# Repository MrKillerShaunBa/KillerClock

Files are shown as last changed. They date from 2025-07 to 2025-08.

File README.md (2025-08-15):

# KillerClock

This is a Nixie tube-inspired clock made using LED filaments. These filaments are strings of micro-LEDs which imitate the look of a tungsten filament. It uses ESP-32, which syncs time with an NTP server using the on-board wifi. It uses a MAX7219 ic to run the 7 segments. Everything is powered using a 5V 2A wall adaptor. There are also Glass test tubes to match the look of a Nixie tube.

I got the inspiration when I chanced upon a [Nixie tube clock](https://nixieshop.com/), which I found very interesting. Since Nixie tubes aren't available reliably in India, I made one using LEDs.

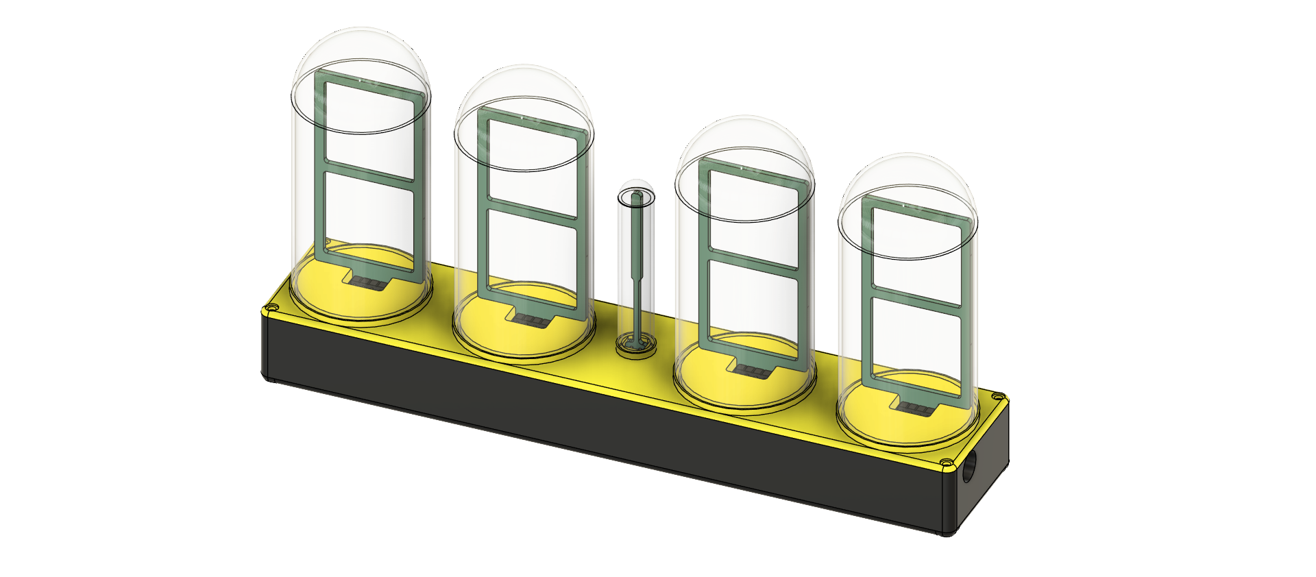
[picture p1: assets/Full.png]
Full


## CAD

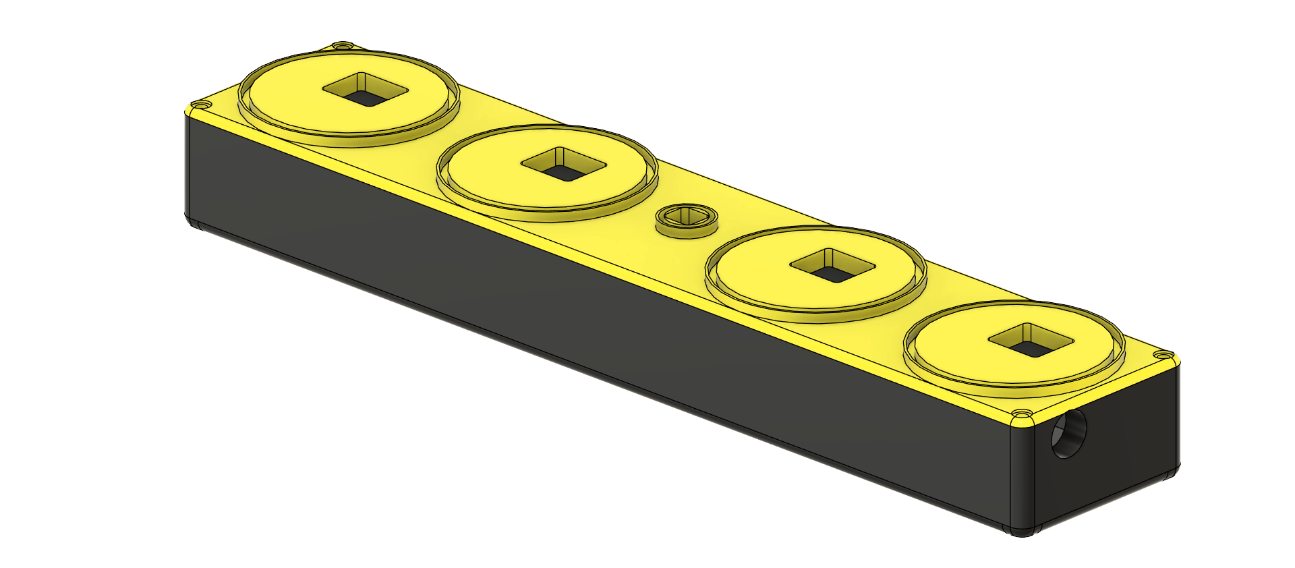
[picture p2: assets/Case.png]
Case


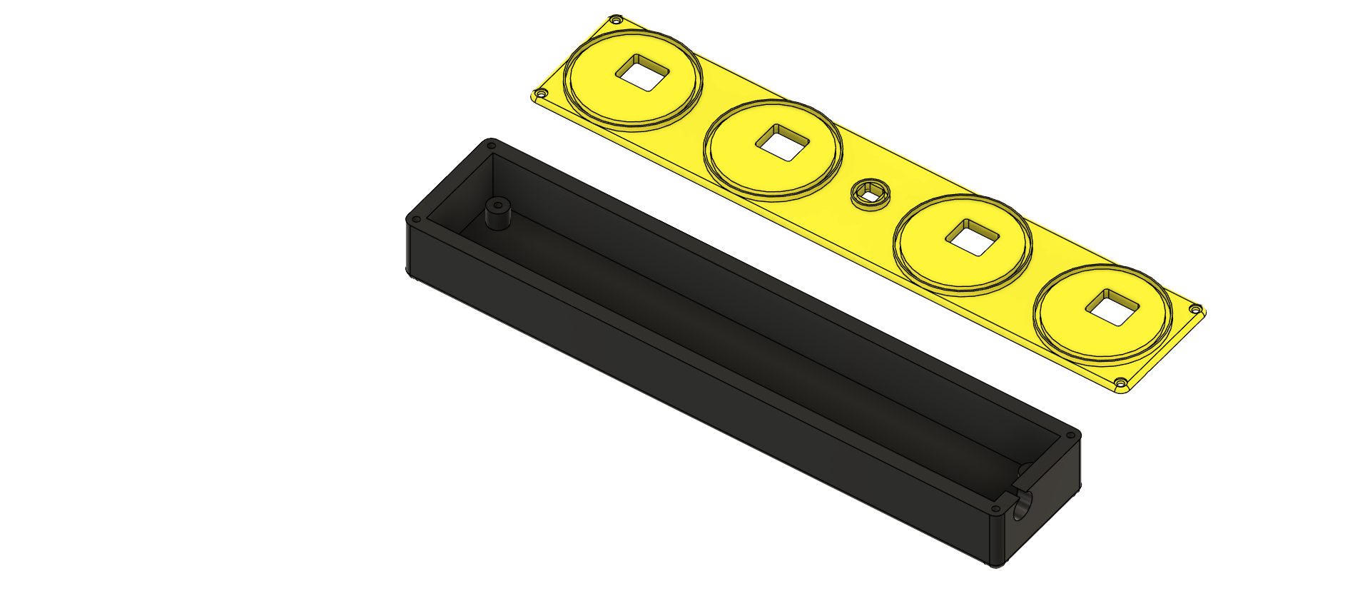
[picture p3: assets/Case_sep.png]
Case Parts


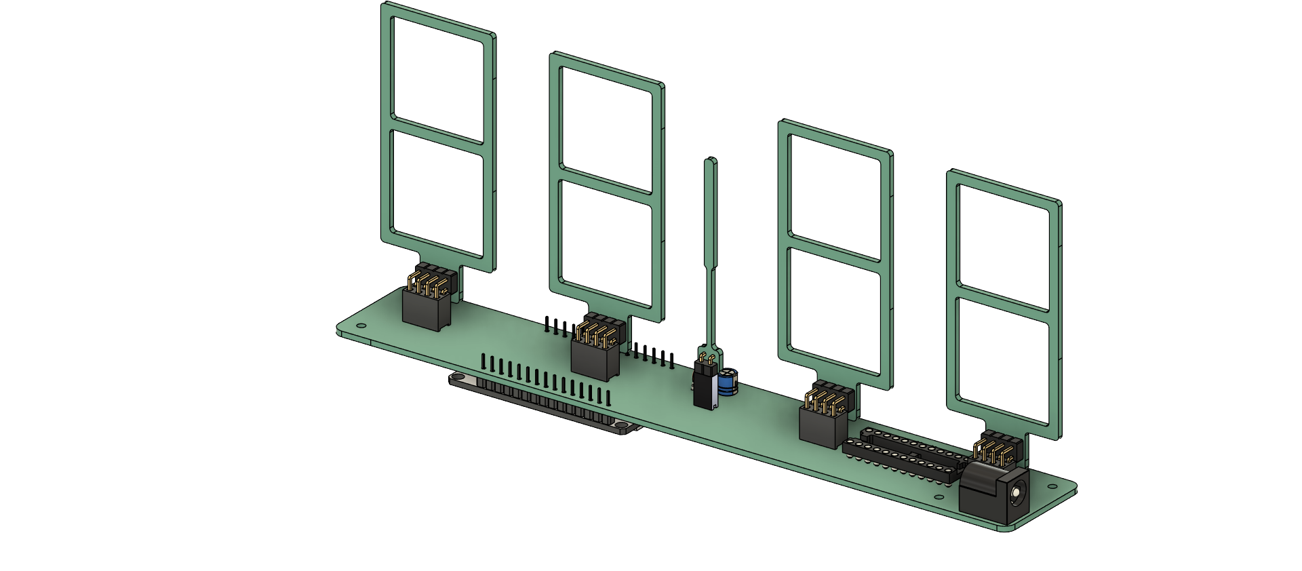
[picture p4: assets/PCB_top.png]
PCB Top


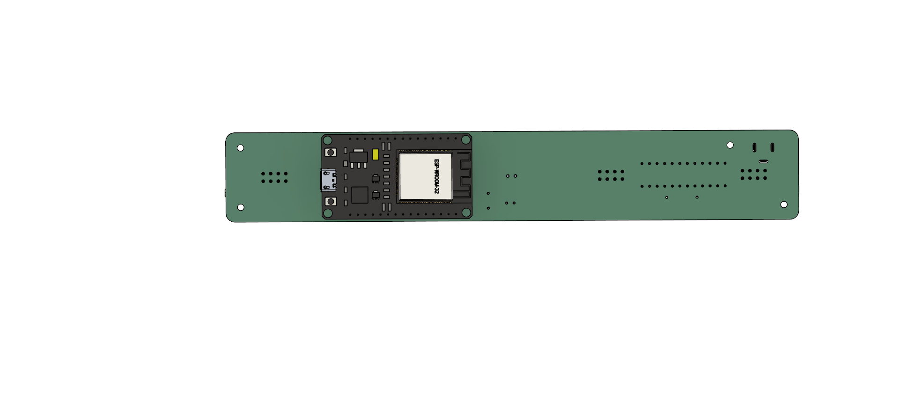
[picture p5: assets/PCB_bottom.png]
PCB Bottom


## PCB

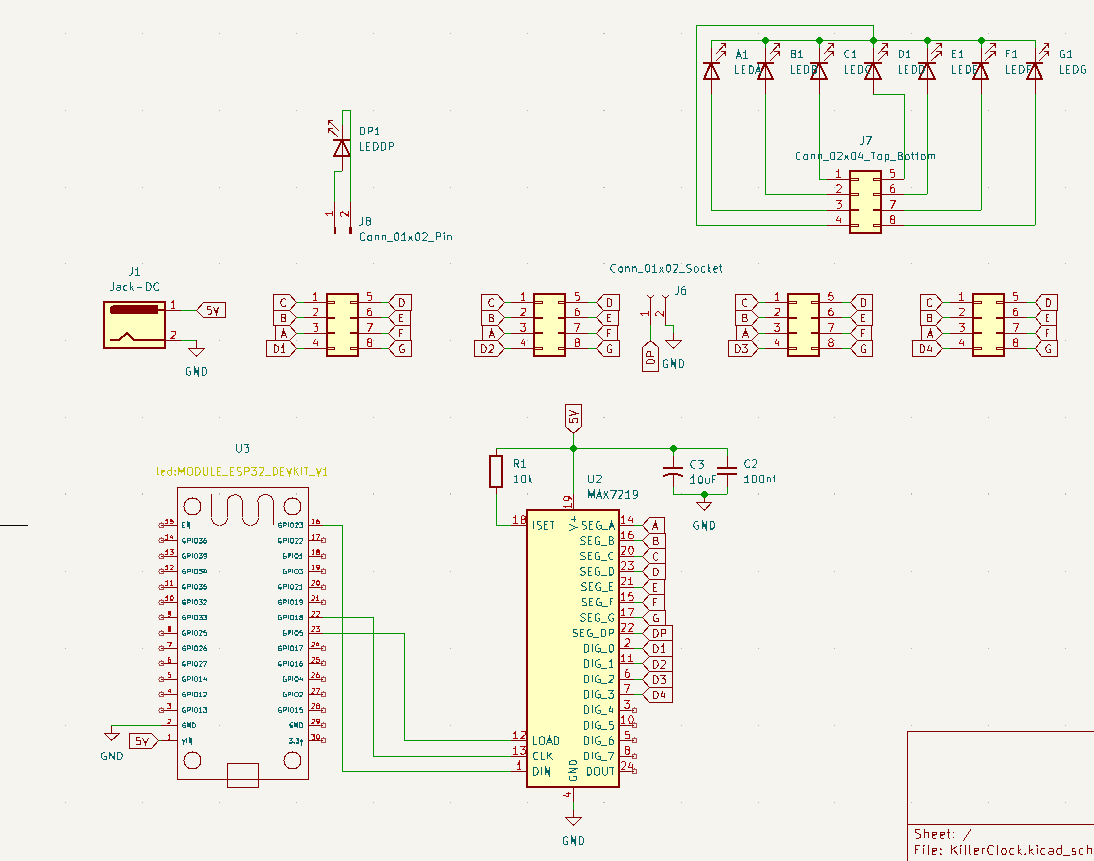
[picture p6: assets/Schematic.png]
Schematic


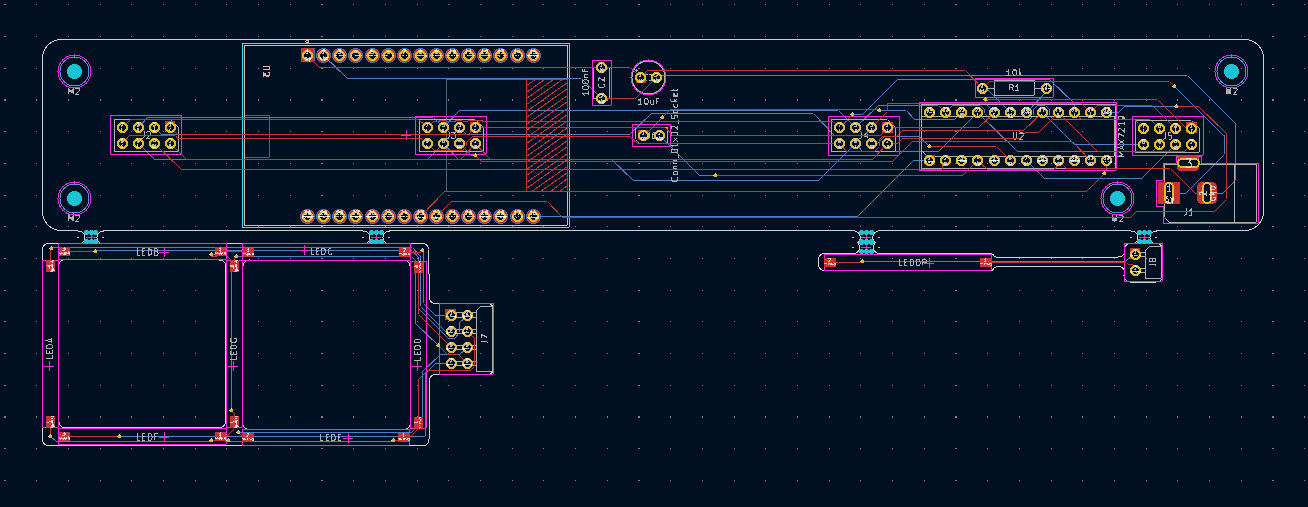
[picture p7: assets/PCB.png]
PCB


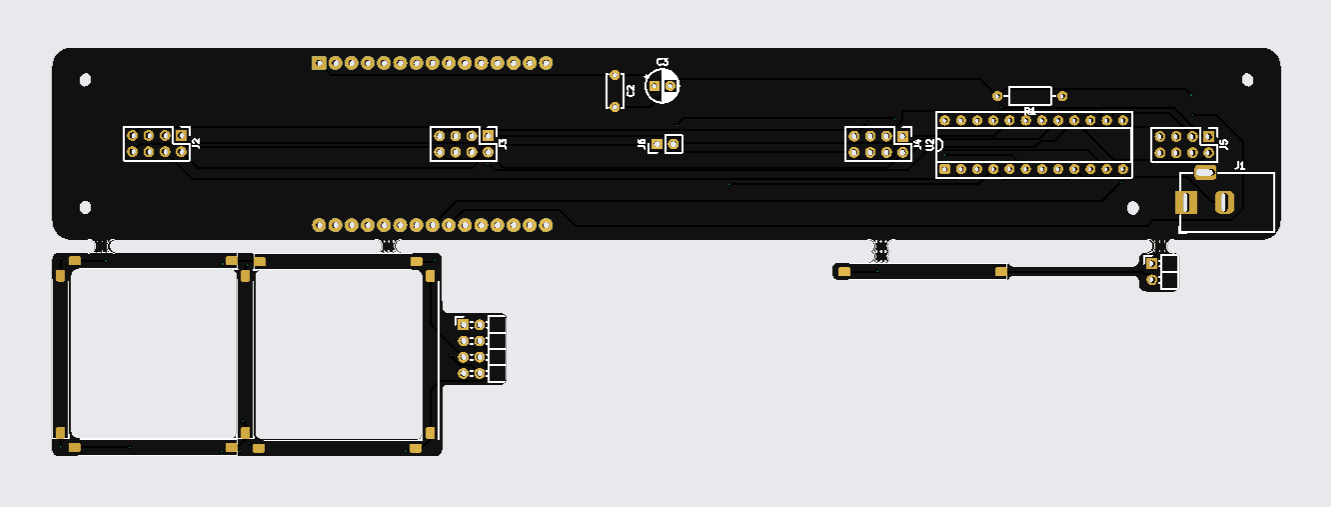
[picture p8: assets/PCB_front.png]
PCB Front


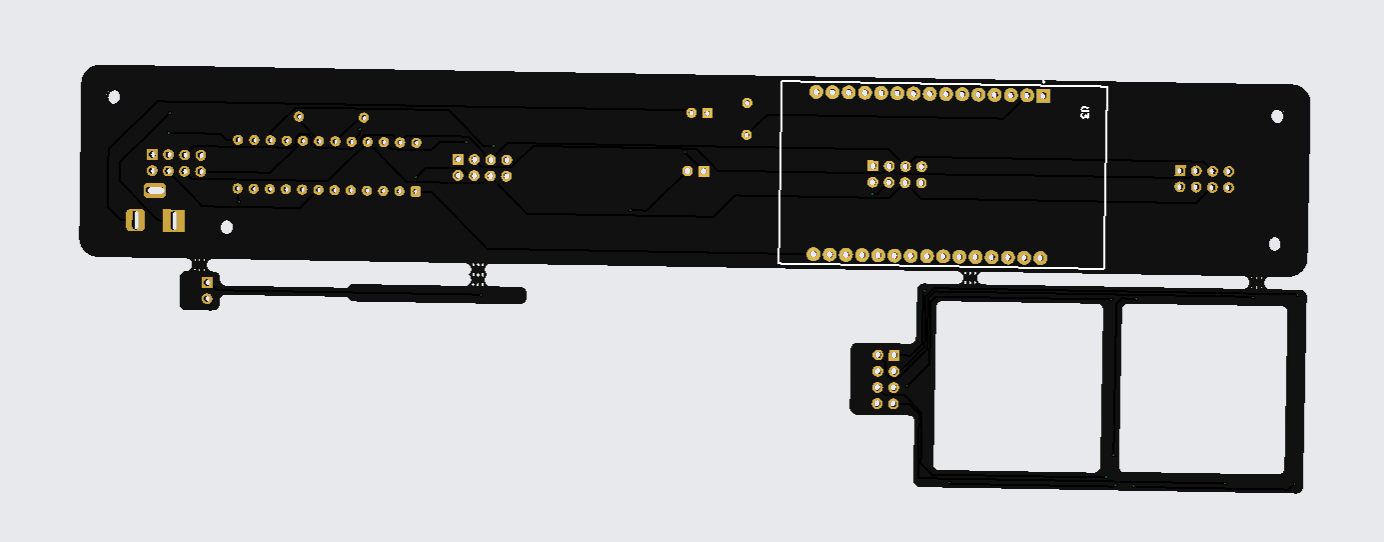
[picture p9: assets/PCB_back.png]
PCB Back


# BOM
| Product | Quantity (MOQ) | Source | Total Price(INR)(includes tax) | Price($)(Converted) | Link |
| :-----: | :-----: | :-----: | :-----: | :-----: | :-----: |
| MAX7219 8-Digit LED Display Driver IC | 2 | eBhoot | 225 | 2.60 | [here](https://ebhoot.in/shop-2/ics/driver-interface-ic/max7219-8-digit-led-display-driver-ic/) |
| DC Power Jack Female | 2 | eBhoot | 14.6 | 0.17 | [here](https://ebhoot.in/shop-2/connectors/dc-005-dc-power-jack-female-adapter-pcb-mount-2-1-x-5-5mm/) |
| ESP32 Development Board | 1 | eBhoot | 377.6 | 4.37 | [here](https://ebhoot.in/shop-2/esp-wifi-boards/esp32-development-board-type-c-usb-ch340c-wifi-bluetooth-ultra-low-power-dual-core/) |
| 10uF 25V Electrolytic Capacitor | 3 | eBhoot | 5.31 | 0.061 | [here](https://ebhoot.in/shop-2/electronics-components/capacitors/10uf-25v-electrolytic-capacitor/) |
| 0.1uF Ceramic Capacitor | 5 | eBhoot | 5.3 | 0.061 | [here](https://ebhoot.in/shop-2/electronics-components/capacitors/0-1uf-104-ceramic-capacitor/) |
| 10K Ohm Resistor | 10 | eBhoot | 5.9 | 0.068 | [here](https://ebhoot.in/shop-2/electronics-components/resistors/10k-ohm-0-25watt-carbon-film-resistor/) |
| 5v-2A DC adaptor | 1 | eBhoot | 123.9 | 1.43 | [here](https://ebhoot.in/shop-2/power-supply/adapters/5v-2a-dc-adapter-with-led-dual-pin-dc/) |
| Ebhoot Shipping | ~ | eBhoot | 90 | 1.04 | ~ |
| 40×2 Pin Male Berg Strip | 2 | Sharvi | 28.91 | 0.33 | [here](https://sharvielectronics.com/product/40x2-pin-male-berg-strip-break-away-header-right-angle-2-54mm-pitch/) |
| 40x1 Pin Male Berg Strip | 1 | Sharvi | 6.8 | 0.079 | [here](https://sharvielectronics.com/product/40x1-pin-male-10mm-height-berg-header-straight-2-54mm-pitch/) |
| 40x1 Pin Female Berg Strip | 1 | Sharvi | 9.7 | 0.11 | [here](https://sharvielectronics.com/product/40x1-pin-female-berg-strip-break-away-header-straight-2-54mm-pitch/) |
| 2x4 pin female berg strip | 5 | Sharvi | 49.7 | 0.57 | [here](https://sharvielectronics.com/product/2x4-8pin-female-berg-strip-break-away-header-straight-2-54mm-pitch/) |
| 24 Pin IC Base | 5 | Sharvi | 29.3 | 0.34 | [here](https://sharvielectronics.com/product/24-pin-ic-base-for-dip-24-package/) |
| M2x6mm Allen bolt | 10 | Sharvi | 112.7 | 1.30 | [here](https://sharvielectronics.com/product/m2x6mm-allen-socket-head-cap-bolt-mild-carbon-steel/) |
| M2x20mm Allen Bolt | 10 | Sharvi | 163.5 | 1.89 | [here](https://sharvielectronics.com/product/m2x20mm-allen-socket-head-cap-bolt-mild-carbon-steel/) |
| M2X3mm Brass Heat Insert | 10 | Sharvi | 33.7 | 0.39 | [here](https://sharvielectronics.com/product/m2x3-mm-brass-heat-set-threaded-round-insert-nut/) |
| Sharvi Shipping | ~ | Sharvi | 75 | 0.87 | ~ |
| LED Filament 3V 26mm | 11*3 | Adafruit | ~ | 54.34 | [here](https://www.adafruit.com/product/5505) (Not available in this size anywhere in India; Inclues tax and shipping) |
| 38x200mm test tubes | 12 | Amazon | 990 | 11.45 | [here](https://amzn.in/d/gJka92f) |
| 10x75mm test tubes | 6 | Amazon | 179 | 2.04 | [here](https://amzn.in/d/571r95v) |
| PCB | 5 | JLC PCB | | 20 | Used coupon and includes shipping | 
| Case | 1 | Print Legion | | ~5 | Only Shipping |

Total Cost- $115-120

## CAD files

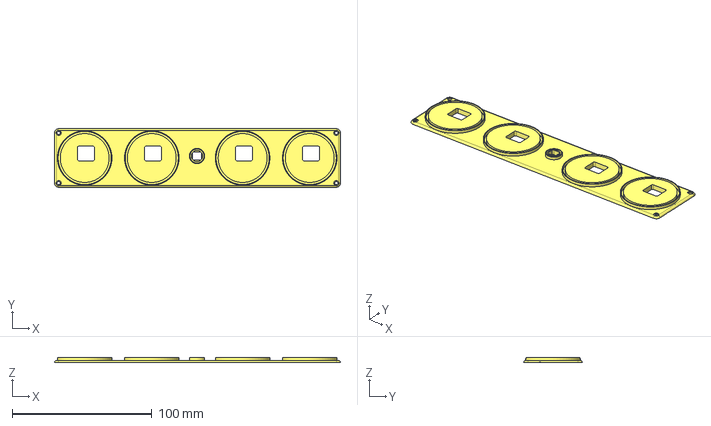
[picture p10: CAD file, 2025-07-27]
Production/Top.step
204.6 x 42.0 x 3.50 mm

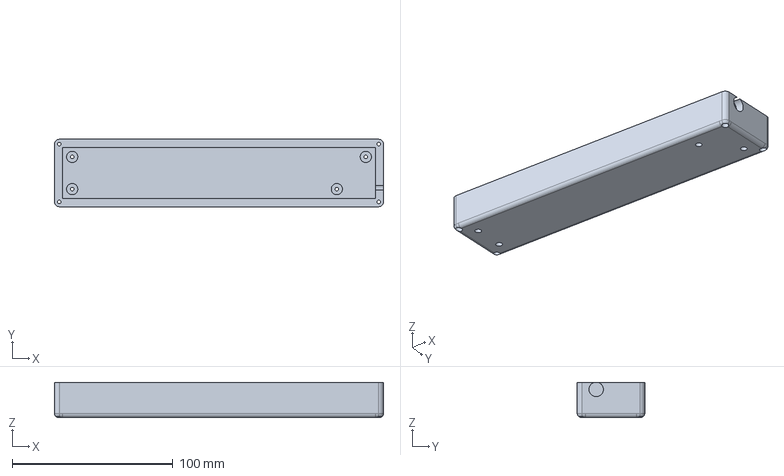
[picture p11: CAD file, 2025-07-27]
Production/Base.step
204.6 x 42.0 x 21.8 mm

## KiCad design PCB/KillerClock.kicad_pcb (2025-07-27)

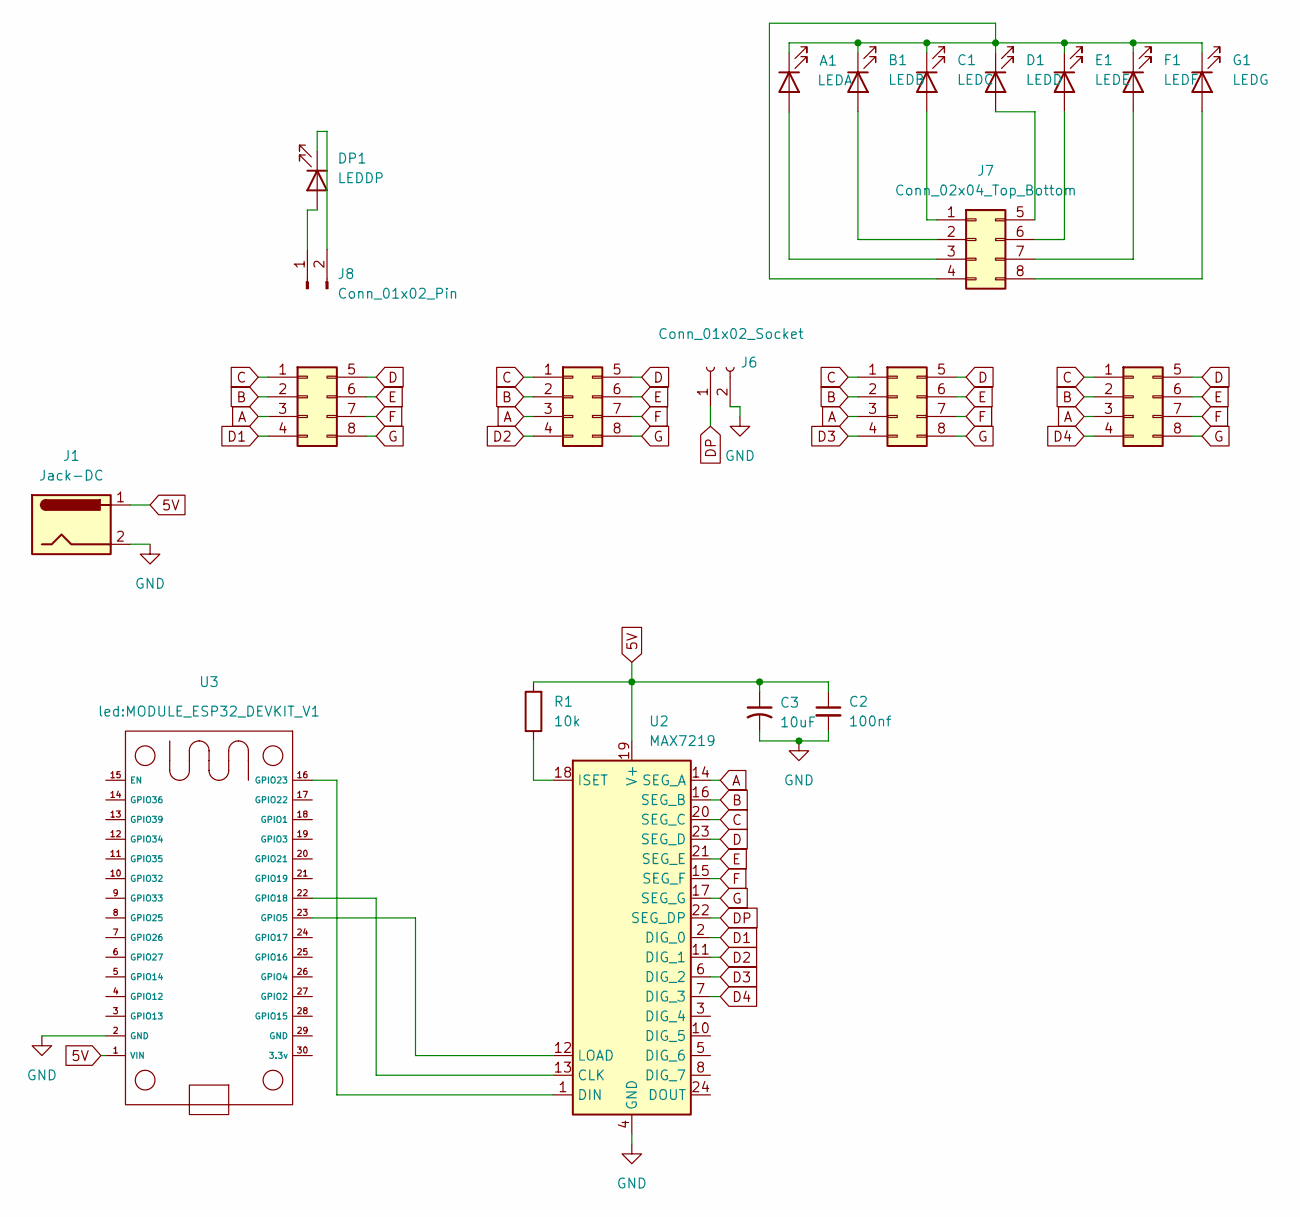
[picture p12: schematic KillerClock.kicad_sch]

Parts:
A1: LEDA; 7SEG
B1: LEDB; 7SEG
C1: LEDC; 7SEG
C2: 100nf; C_Disc_D5.0mm_W2.5mm_P5.00mm
C3: 10uF; CP_Radial_D5.0mm_P2.50mm
D1: LEDD; 7SEG
DP1: LEDDP; 7SEG
E1: LEDE; 7SEG
F1: LEDF; 7SEG
G1: LEDG; 7SEG
J1: Jack-DC; BarrelJack_Horizontal
J2, J3, J4, J5: Conn_02x04_Top_Bottom; PinHeader_2x04_P2.54mm_Vertical
J6: Conn_01x02_Socket; PinHeader_1x02_P2.54mm_Vertical
J7: Conn_02x04_Top_Bottom; PinHeader_2x04_P2.54mm_Horizontal
J8: Conn_01x02_Pin; PinHeader_1x02_P2.54mm_Horizontal
R1: 10k; R_Axial_DIN0207_L6.3mm_D2.5mm_P10.16mm_Horizontal
U2: MAX7219; DIP-24_W7.62mm_Socket
U3: MODULE_ESP32_DEVKIT_V1

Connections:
5V: C2.1, C3.1, J1.1, R1.2, U2.19 (V+), U3.1 (VIN)
A: J2.3, J3.3, J4.3, J5.3, U2.14 (SEG_A)
B: J2.2, J3.2, J4.2, J5.2, U2.16 (SEG_B)
C: J2.1, J3.1, J4.1, J5.1, U2.20 (SEG_C)
D: J2.5, J3.5, J4.5, J5.5, U2.23 (SEG_D)
D1: J2.4, U2.2 (DIG_0)
D2: J3.4, U2.11 (DIG_1)
D3: J4.4, U2.6 (DIG_2)
D4: J5.4, U2.7 (DIG_3)
DP: J6.1, U2.22 (SEG_DP)
E: J2.6, J3.6, J4.6, J5.6, U2.21 (SEG_E)
F: J2.7, J3.7, J4.7, J5.7, U2.15 (SEG_F)
G: J2.8, J3.8, J4.8, J5.8, U2.17 (SEG_G)
GND: C2.2, C3.2, J1.2, J6.2, U2.4 (GND), U2.9 (GND), U3.2 (GND)
unnamed: A1.2 (A), J7.3
unnamed: A1.1 (K), B1.1 (K), C1.1 (K), D1.1 (K), E1.1 (K), F1.1 (K), G1.1 (K), J7.4
unnamed: B1.2 (A), J7.2
unnamed: C1.2 (A), J7.1
unnamed: D1.2 (A), J7.5
unnamed: DP1.2 (A), J8.1
unnamed: DP1.1 (K), J8.2
unnamed: E1.2 (A), J7.6
unnamed: F1.2 (A), J7.7
unnamed: G1.2 (A), J7.8
unnamed: U2.13 (CLK), U3.22 (GPIO18)
unnamed: U2.1 (DIN), U3.16 (GPIO23)
unnamed: R1.1, U2.18 (ISET)
unnamed: U2.12 (LOAD), U3.23 (GPIO5)

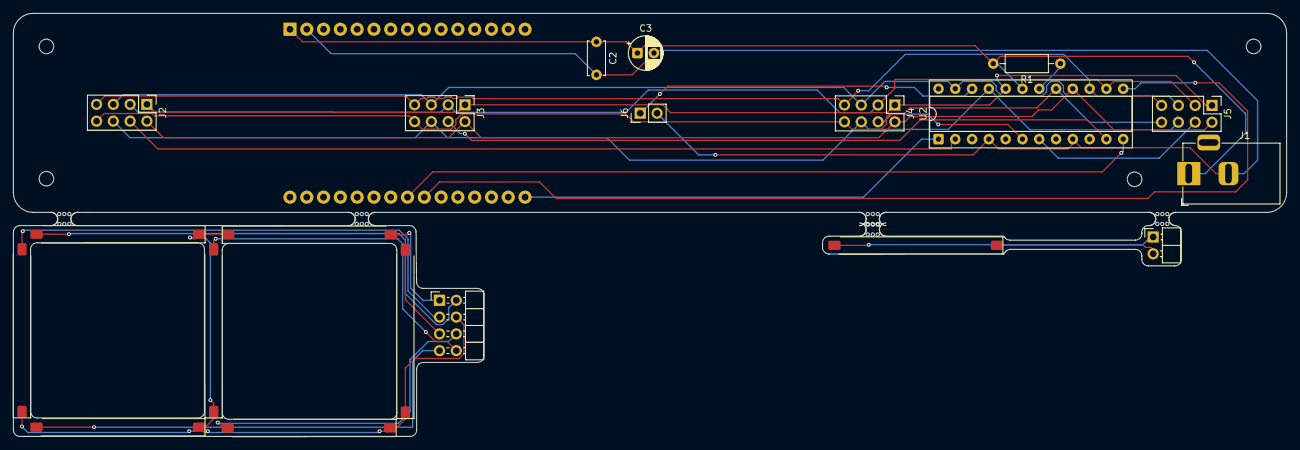
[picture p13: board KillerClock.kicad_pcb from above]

Board: 2 copper layers, 192.6 x 64.0 mm, 26 parts (1 on the bottom side), 28 nets.

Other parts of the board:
mouse-bite-2mm-slot, mouse-bite-2mm-slot#2, mouse-bite-2mm-slot#3, mouse-bite-2mm-slot#4, mouse-bite-2mm-slot#5: VAL**; mouse-bite-2mm-slot

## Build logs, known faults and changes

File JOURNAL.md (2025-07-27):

---
title: "KillerClock"
author: "Shuanak Bajaj"
description: "Making a Nixie tube-inspired clock but using LED"
created_at: "2025-07-25"
---

### Total Time Spent: 18.5h

# July 25th: Getting to work after I got an Idea!

I was drooling at Nixie tube clocks but those arent available in India ;-; Then I got an idea, why not make it out of LEDs. Turns out, it wasnt so original, people have attempted it [before](https://www.reddit.com/r/electronics/comments/wgo8go/made_another_bigger_led_filament_tube_clock/). But I wasnt able to find any intructions, BOM, or schematic. So I am trying to create my own LED clock.

My inspiration-


I would be using LED filaments (Adafruit nooodles kind) to create 7 segment displays which would be mounted vertically onto a PCB. I would run it using a ESP 32 and connect it to the internet for time syncing.

Have started making the schemtatic. Since the 7segment LEDs are wired in a grid pattern, I will use a MAX7219 ic to controll them which is also widely used in commericial matrix displays. I want the numbers to be vertical, therfore I have added 4 2x4 connectors and wired them.



The single led in between is for the separation between hours and minutes.

**Total time spent: 4h**

# July 26th: Schematic Complete, onto the more difficult part

Made the schematic. Turns out that the symbol for ESP32 was the wrong one. So I had to import the correct one from the internet.




Idk why but it took me a lot of time to find the right footprints for all the components, I even had to define a custom footprint for my led filament.



I finally started making the schmatic. With a lot of vias, I was able to wire the numeric display.



I had placed the connectors too closely at first then I realsied that the led panels would clash with each other. I i had to remove all the wiring and re-place them with corret distances. Now I have also taken into account the size of the test tubes that will be going over them.



Wired the MAX7219 with the connectors. Became very complex very fast. Just need to complete the esp32 and well be done.



Finally finished the the schematic. Watched a video about adding mouse bites to combine the different parts. Will do that.



Added mouse bites, filets and mounting holes. Moving now to making a case for my clock.







The male pins on the pcb are wrong here, will fix them in Fusion.

Finalized the bom and started a sketch in Fusion 360.





**Total time spent: 7.5h**

July 27th: Cadding all the way

Made a base with holes for m2 screws and heatset inserts.



Imported the PCB, aligned and join all pieces. Had to work a lot since the PCB was joined together, as you can see above. So I used split body tool on the faces and then extruded out the rat holes part. 



Added mounting holes in the bottom for the PCB.



I have made them in such a way that the hatset inserts are added from the bottom.



Created a top for the case. Added cutouts for the numbers to be inserted from top.


Created test tubes in fusion :/ Took a while to get it right.



Added grooves for fitting the set tube.





Added fillets everywhere.



Added a hole for the power supply.



With that this is ready (except forthe firmware).



Wrote the firmware and redied all the files for submission.



**Total time spent: 7h**

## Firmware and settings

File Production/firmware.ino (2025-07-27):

#include <WiFi.h>
#include <NTPClient.h>
#include <WifiUdp.h>
#include <SPI.h>
#include <LedControl.h>

#define CLK_PIN   18 
#define DATA_PIN  23 
#define CS_PIN    5

LedControl lc = LedControl(DATA_PIN, CLK_PIN, CS_PIN, 1);

const char* ssid     = "<will add later>";
const char* password = "<will add later>";

WiFiUDP ntpUDP;
NTPClient timeClient(ntpUDP, "pool.ntp.org", 19800, 3600000);

unsigned long lastSyncMillis = 0;
unsigned long syncInterval = 3600000;
unsigned long localMillisAtSync = 0;
int syncedHour = 0;
int syncedMinute = 0;
int syncedSecond = 0;

void setup() {
  Serial.begin(115200);
  WiFi.begin(ssid, password);
  while (WiFi.status() != WL_CONNECTED) {
    delay(500);
    Serial.print("Connecting.");
  }
  Serial.println("");
  Serial.println("WiFi connected.");
  timeClient.begin();
  lc.shutdown(0, false);
  lc.setIntensity(0, 8);
  lc.clearDisplay(0);
}

void loop() {
  if (millis() - lastSyncMillis >= syncInterval) {
    syncTime();
  }
  displayTime();
  delay(1000);
}

void syncTime() {
  Serial.println("Syncing time with NTP...");
  timeClient.update();

  syncedHour = timeClient.getHours();
  syncedMinute = timeClient.getMinutes();
  syncedSecond = timeClient.getSeconds();

  localMillisAtSync = millis();
  lastSyncMillis = millis();

  Serial.printf("Time synced: %02d:%02d:%02d\n", syncedHour, syncedMinute, syncedSecond);
}

void getCurrentTime(int &hours, int &minutes, int &seconds) {
  unsigned long elapsed = (millis() - localMillisAtSync) / 1000;
  int totalSeconds = syncedSecond + elapsed;
  minutes = syncedMinute + totalSeconds / 60;
  seconds = totalSeconds % 60;
  hours = (syncedHour + minutes / 60) % 24;
  minutes = minutes % 60;
}

void displayTime(){
  int hours, minutes, seconds;
  getCurrentTime(hours, minutes, seconds);
  int h1 = hours / 10;
  int h2 = hours % 10;
  int m1 = minutes / 10;
  int m2 = minutes % 10;

  bool colonOn = (millis() / 1000) % 2 == 0;

  lc.setDigit(0,3,h1,false);
  lc.setDigit(0, 2, h2, colonOn);
  lc.setDigit(0, 1, m1, false);
  lc.setDigit(0, 0, m2, false);
}
